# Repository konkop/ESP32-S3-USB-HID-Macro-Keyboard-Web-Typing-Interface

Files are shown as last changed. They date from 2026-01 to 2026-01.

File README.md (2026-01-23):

# ESP32-S3 USB HID Macro Keyboard + Web Typing Interface

This project turns an ESP32-S3 into a USB HID keyboard with a built-in web interface that can type text into another computer in a human-like way and trigger macro commands using physical Cherry MX keys.
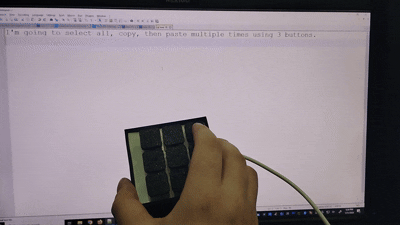
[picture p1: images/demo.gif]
Demo

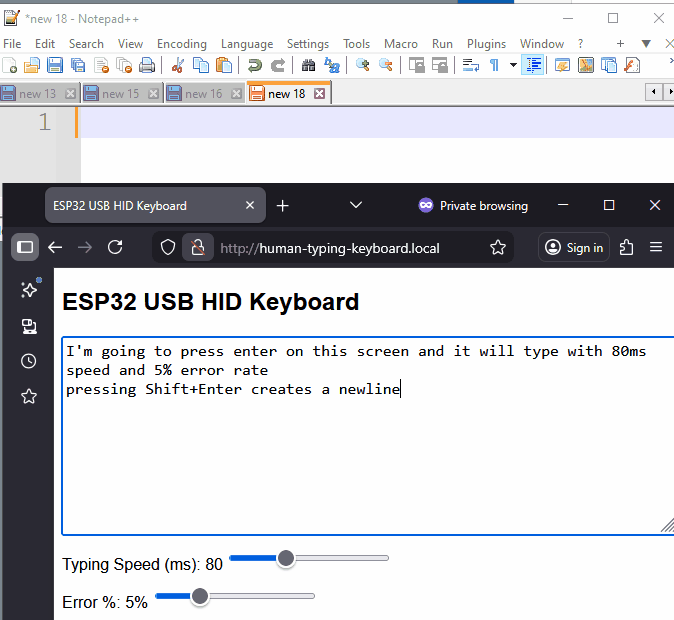
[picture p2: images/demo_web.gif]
Demo2

---

## Features

- USB HID Keyboard (TinyUSB)
- No drivers needed on destination machine so works on any OS(literally everything: Windows, Linux, Mac, Android, Chrome OS, smart TVs, etc.)
- Web interface hosted on the ESP32
- Press Enter to send text (Shift+Enter inserts newline)
- Human-like typing (random delays, pauses, backspaces)
- 9 physical Cherry MX macro keys
- Can skip physical keys for just remote typing
- Debounced button handling
- Serial debug output
- mDNS support (.local address)
- PlatformIO compatible

---

## Hardware Required

### Main Board
- ESP32-S3 development board with native USB
- Tested with: ESP32-S3 DevKit (N16R8)
  - https://www.amazon.com/dp/B0CKXJLP4B

### Buttons
- 9x Cherry MX switches
  - https://www.amazon.com/dp/B0DSHTPSL3
- Optional keycaps

### Wiring
- Jumper wires
- USB-C data cables (must support data, not power-only)

---

## GPIO Pin Mapping (Physical Keys)

Each Cherry MX switch connects between a GPIO pin and GND.
Internal pull-ups are used (INPUT_PULLUP).

| Button | GPIO | Action |
|---|---|---|
| 1 | GPIO 4 | Ctrl + C |
| 2 | GPIO 5 | Ctrl + V |
| 3 | GPIO 12 | Ctrl + A |
| 4 | GPIO 13 | KEEP ALIVE -> www.google.com (win only) |
| 5 | GPIO 14 | Alt + Tab |
| 6 | GPIO 15 | Ctrl + X |
| 7 | GPIO 16 | Ctrl + Alt + Del (delay) enter |
| 8 | GPIO 17 | Ctrl + S |
| 9 | GPIO 18 | Ctrl + P |

### Wiring Diagram (Concept)

GPIO ----[ Cherry MX Switch ]---- GND

- Button pressed = LOW
- Button released = HIGH
- No external resistors required

---

## Software Setup (PlatformIO)

### Install Tools
- Visual Studio Code
- PlatformIO extension
---

## Wi-Fi Configuration

Edit main.cpp and set your Wi-Fi credentials:

const char* ssid = "YOUR_WIFI_NAME";
const char* password = "YOUR_WIFI_PASSWORD";

---

## Uploading and Running

### USB Connections

- UART / COM port: flashing firmware and Serial Monitor
- Native USB port: HID keyboard device

Both ports can be connected to the same computer at the same time.

### Upload Firmware

Use PlatformIO "Upload".

### Serial Monitor

Use PlatformIO "Monitor".

Expected output:

WiFi Connected
IP Address: xxx.xxx.xxx.xxx
http://human-typing-keyboard.local

---

## Web Interface

Open the following in your browser:

http://human-typing-keyboard.local

- Press Enter to send text and clears the textbox
- Shift + Enter inserts a newline

---

## Physical Macro Keys

- Each key triggers once per press
- Fully debounced in software
- Serial output confirms key presses

---

## Debugging Notes

- Buttons are active LOW
- HIGH = unpressed
- LOW = pressed
- Use Serial output to verify wiring

---

## Notes

- ESP32-S3 supports 2.4 GHz Wi-Fi only
- Many USB-C cables are power-only — use data-capable cables
- HID typing controls your computer — use with caution
- This is built as a demonstration use at your own risk. I take no responsiblity for actions with this device.

---

## Future Improvements

- Web-configurable macros
- Key remapping
- OLED display support

---

## License

MIT License

---

## Credits

- ESP32 Arduino Core
- TinyUSB
- PlatformIO

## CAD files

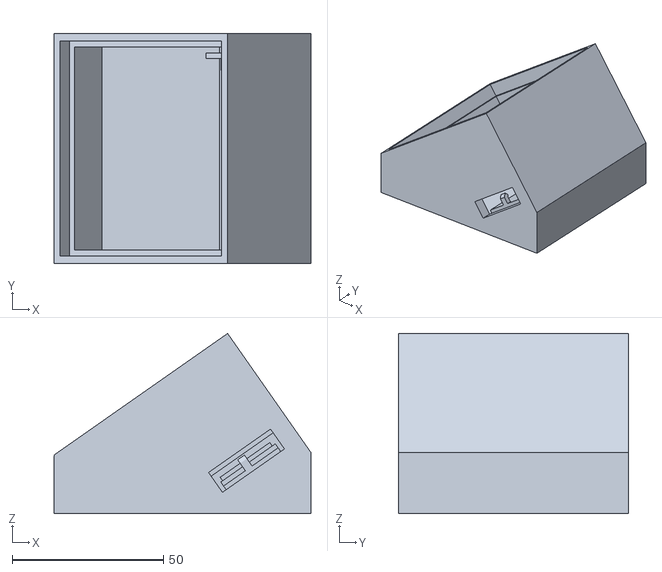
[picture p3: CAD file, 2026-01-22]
ENCLOSURE/body.stl
84.9 x 76.0 x 59.5

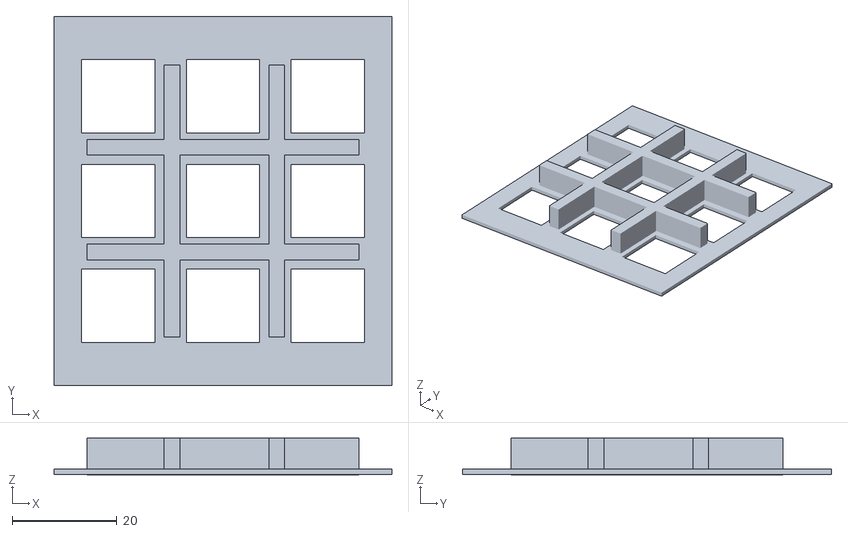
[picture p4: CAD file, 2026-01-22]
ENCLOSURE/key panel.stl
64.5 x 70.5 x 7.00

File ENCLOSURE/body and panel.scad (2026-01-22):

showBody=true;
showPanel=false;

//panel
if(showPanel){
    difference(){
    cube([70-5-.5,76-5-.5,1]);

    translate([5.25,8.25,0])
    for (row = [1 : 3])
        for (col = [1 : 3]) {
            translate([(col-1)*20, (row-1)*20, -.1])
            cube([14,14,6]);
        }
    }
    for (col = [1 : 2]) {
        translate([(col-1)*20+21, 9.25, -.1])
        cube([3,52,7]);
        
        
        translate([6.25, (col-1)*20+27, -.1])
        rotate([0,0,-90])
        cube([3,52,7]);
    }
}


//The main body
if(showBody){
union(){
    hull(){
    cube([1,76,1]);
    translate([0,0,18])
    cube([1,76,1]);
    translate([18,0,0])
    cube([1,76,1]);
    }
    hull(){
    translate([83.85,0,0])
    cube([1,76,1]);
    translate([83.85,0,19.2])
    cube([1,76,1]);

    translate([55,0,0])
    cube([1,76,1]);
    }



    cube([83.85,76,4.5]);

    translate([27.5,0,-20])
    rotate([0,-35,0])
    union(){
        difference(){
            cube([70,76,48]);
            //main cutout
            translate([9/2,9/2,4.5])
            cube([70-9,76-9,48-4.4]);
            
            //lip for cover
            translate([5/2,5/2,48-5.49])
            cube([70-5,76-5,5.5]);
            
            //usb cutout
            translate([70-25-7.5,-.1,4])
            cube([28,10,12]);
            
            //45 on main box
            translate([0,-.1,-70])
            rotate([0,-55,0])
            cube([80,80,80]);
        }
        //board
        translate([70-5,4.5,4])
        rotate([0,0,90])
        union(){
            baseheight=.5;
            basewidth=65;
            cube([basewidth,28.5,baseheight]);
            translate([0,(28.5-22.5)/2,0])
            cube([basewidth-5.8,22,3+baseheight]);
            translate([basewidth-5.8,(28.5-22.5)/2,0])
            cube([4,22,3+baseheight+1.6]);


            //end board
            translate([basewidth-5.8,(28.5-22.5)/2,0])
            cube([4,18,3+baseheight+1.6]);
            translate([basewidth-5.8+4,0,0])
            difference(){
                cube([1.8,28.5,3+baseheight+5]);
                translate([-.1,(28.5-20)/2,3+baseheight+1.5])
                cube([3,20,1.5]);
            }

            //front board clip
            translate([0,29/2-1,3+baseheight])
            union(){
                cube([2,2.7,3]); 
                translate([0,0,3])   
                rotate([0,45,0])
                cube([1.7,2.7,2]);
            }
        }
    }
}
}

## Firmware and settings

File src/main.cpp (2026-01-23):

#include <Arduino.h>
#include <WiFi.h>
#include <WebServer.h>

#include "USB.h"
#include "USBHIDKeyboard.h"
#include <ESPmDNS.h>

const int NUM_BUTTONS = 9;
const int debounceDelay = 200; // milliseconds

int buttonPins[NUM_BUTTONS] = {4,5,12,13,14,15,16,17,18};
bool lastButtonState[NUM_BUTTONS];
unsigned long lastDebounceTime[NUM_BUTTONS];
bool typingInProgress = false;

int typingSpeedMs = 80;     // base delay between keystrokes
int errorPercent = 5;      // percent chance of typo

bool keepAliveEnabled = false;
unsigned long lastKeepAliveTime = 0;
const unsigned long KEEP_ALIVE_INTERVAL = 5UL * 60UL * 1000UL; // 5 minutes

// ================= USB HID ================= 

USBHIDKeyboard Keyboard;

// ================= WIFI ================= 

const char* ssid = "YOUR_WIFI_NAME";
const char* password = "YOUR_WIFI_PASSWORD";

WebServer server(80);

String textBuffer;
bool startTyping = false;

// ================= HTML ================= 

const char* htmlPage = R"rawliteral(
<!DOCTYPE html>
<html>
<head>
  <title>ESP32 USB HID Keyboard</title>
  <style>
    body { font-family: Arial; }
    textarea { width: 100%; font-size: 16px; }
    .slider-container { margin-top: 10px; }
    label { display: block; margin-top: 10px; }
  </style>

  <script>
    document.addEventListener("DOMContentLoaded", function() {
      const textarea = document.getElementById("inputText");
      const speedSlider = document.getElementById("speed");
      const errorSlider = document.getElementById("error");
      const speedValue = document.getElementById("speedValue");
      const errorValue = document.getElementById("errorValue");

      speedValue.textContent = speedSlider.value;
      errorValue.textContent = errorSlider.value;

      speedSlider.oninput = () => speedValue.textContent = speedSlider.value;
      errorSlider.oninput = () => errorValue.textContent = errorSlider.value;

      textarea.addEventListener("keydown", function(e) {
        if (e.key === "Enter" && !e.shiftKey) {
          e.preventDefault();
          sendText();
        }
      });

      function sendText() {
        const text = textarea.value;
        if (!text || text.trim().length === 0) return;

        const params =
          "text=" + encodeURIComponent(text) +
          "&speed=" + speedSlider.value +
          "&error=" + errorSlider.value;

        var xhr = new XMLHttpRequest();
        xhr.open("POST", "/send", true);
        xhr.setRequestHeader("Content-type", "application/x-www-form-urlencoded");
        xhr.send(params);

        textarea.value = "";
        textarea.focus();
      }
    });
  </script>
</head>

<body>
  <h2>ESP32 USB HID Keyboard</h2>

  <textarea id="inputText" rows="10"
    placeholder="Enter = send | Shift+Enter = newline"></textarea>

  <div class="slider-container">
    <label>
      Typing Speed (ms): <span id="speedValue"></span>
      <input type="range" id="speed" min="20" max="200" value="80">
    </label>

    <label>
      Error %: <span id="errorValue"></span>%
      <input type="range" id="error" min="0" max="20" value="5">
    </label>
  </div>
</body>
</html>
)rawliteral";


// ================= HUMAN TYPING ================= 

void runKeepAlive() {
  Serial.println("KEEP ALIVE: Launching Edge");

  // Win + R
  Keyboard.press(KEY_LEFT_GUI);
  Keyboard.press('r');
  Keyboard.releaseAll();
  delay(300);

  // Type Edge command
  Keyboard.print("msedge https://www.google.com");
  delay(100);

  // Enter
  Keyboard.press(KEY_RETURN);
  Keyboard.release(KEY_RETURN);
}

void humanDelay() {
  int jitter = random(-typingSpeedMs / 3, typingSpeedMs / 3);
  delay(max(10, typingSpeedMs + jitter));
}

void typeChar(char c) {
  Keyboard.print(c);
}

void backspace() {
  Keyboard.press(KEY_BACKSPACE);
  delay(10);
  Keyboard.release(KEY_BACKSPACE);
}

void humanType(const String& text) {
  for (int i = 0; i < text.length(); i++) {
    humanDelay();

    char c = text[i];

    // 5% typo chance only for letters
    if (random(0, 100) < errorPercent && isalpha(c)) {
      Keyboard.print('x');
      delay(random(40, 120));
      Keyboard.press(KEY_BACKSPACE);
      Keyboard.release(KEY_BACKSPACE);
    }

    if (c == '\n') {
      Keyboard.press(KEY_RETURN);
      delay(10);
      Keyboard.release(KEY_RETURN);
    } else {
      typeChar(c);
    }

    // Natural pauses
    if (c == '.' || c == ',')
      delay(random(300, 700));
    if (c == '\n')
      delay(random(500, 1000));
  }
}

// Map buttons to HID actions (example: Ctrl+C, Ctrl+V...)
void triggerAction(int btn) {

  // ANY button press cancels keep-alive
  if (keepAliveEnabled && btn != 3) {
    keepAliveEnabled = false;
    Serial.println("KEEP ALIVE DISABLED (button activity)");
    return;
  }

  switch (btn) {
    case 0: //button 1
      Serial.println("Button 1 pressed: Ctrl+C");
      Keyboard.press(KEY_LEFT_CTRL);
      Keyboard.press('c');
      delay(50);
      Keyboard.releaseAll();
      break;
    case 1: // Button 2
      Serial.println("Button 2 pressed: Ctrl+V");
      Keyboard.press(KEY_LEFT_CTRL);
      Keyboard.press('v');
      delay(50);
      Keyboard.releaseAll();
      break;
    case 2:// Button 3
      Serial.println("Button 3 pressed: Ctrl+A (Select All)");
      Keyboard.press(KEY_LEFT_CTRL);
      Keyboard.press('a');
      delay(50);
      Keyboard.releaseAll();
      break;
    case 3: // BUTTON 4 → KEEP ALIVE Toggle
      keepAliveEnabled = !keepAliveEnabled;
      lastKeepAliveTime = millis();
      Serial.println("KEEP ALIVE changed");
      break;

    case 4: // BUTTON 5 → Alt + tab
      Keyboard.press(KEY_LEFT_ALT);
      Keyboard.press(KEY_TAB);
      delay(100);
      Keyboard.releaseAll();
      break;
    case 5:
      Serial.println("Button 6 pressed: Ctrl+X (Cut)");
      Keyboard.press(KEY_LEFT_CTRL);
      Keyboard.press('x');
      delay(50);
      Keyboard.releaseAll();
      break;
    case 6:
      Serial.println("Button 7 pressed: Ctrl+Alt+Delete, wait 2s, Enter");

      // Ctrl + Alt + Delete
      Keyboard.press(KEY_LEFT_CTRL);
      Keyboard.press(KEY_LEFT_ALT);
      Keyboard.press(KEY_DELETE);
      delay(100);
      Keyboard.releaseAll();

      // Wait 2 seconds
      delay(2000);

      // Press Enter
      Keyboard.press(KEY_RETURN);
      delay(50);
      Keyboard.release(KEY_RETURN);

      break;
    case 7:
      Serial.println("Button 8 pressed: Ctrl+S (Save)");
      Keyboard.press(KEY_LEFT_CTRL);
      Keyboard.press('s');
      delay(50);
      Keyboard.releaseAll();
      break;
    case 8:
      Serial.println("Button 9 pressed: Ctrl+P (Print)");
      Keyboard.press(KEY_LEFT_CTRL);
      Keyboard.press('p');
      delay(50);
      Keyboard.releaseAll();
      break;
  }
}


// ================= WEB HANDLERS ================= 

void handleRoot() {
  server.send(200, "text/html", htmlPage);
}

void handleSend() {
  textBuffer = server.arg("text");

  if (server.hasArg("speed")) {
    typingSpeedMs = server.arg("speed").toInt();
  }

  if (server.hasArg("error")) {
    errorPercent = server.arg("error").toInt();
  }

  Serial.printf(
    "Received text (%d chars), speed=%dms, error=%d%%\n",
    textBuffer.length(),
    typingSpeedMs,
    errorPercent
  );

  startTyping = true;
  server.send(200, "text/plain", "OK");
}

// ================= SETUP ================= 

void setup() {
  delay(1000);

  Serial.begin(115200);       // Start the Serial Monitor
  while (!Serial) { }         // Wait for Serial to be ready (optional)
  
  Serial.println("Booting ESP32-S3...");
  
  // USB HID
  Keyboard.begin();
  USB.begin();

  WiFi.setHostname("human-typing-keyboard");

  //start wifi
  WiFi.begin(ssid, password);
  Serial.print("Connecting to Wi-Fi ");

  //keep trying wifi
  int retries = 0;
  while (WiFi.status() != WL_CONNECTED) {
      delay(500);
      Serial.print(".");
      retries++;
      if (retries > 20) {  // timeout after 10 seconds
          Serial.println("\nFailed to connect to Wi-Fi!");
          break;
      }
  }

  if (WiFi.status() == WL_CONNECTED) {
      Serial.println("\nWi-Fi Connected!");
      Serial.print("IP Address: ");
      Serial.println(WiFi.localIP());
  }

  //turn on the web server
  server.on("/", handleRoot);
  server.on("/send", HTTP_POST, handleSend);
  server.begin();

  // setup http://human-typing-keyboard.local
  MDNS.begin("human-typing-keyboard");

  for (int i = 0; i < NUM_BUTTONS; i++) {
    pinMode(buttonPins[i], INPUT_PULLUP);
    lastButtonState[i] = HIGH;  // buttons idle HIGH
    lastDebounceTime[i] = 0;
  }

}

// ================= LOOP ================= 

void loop() {
  server.handleClient();

  if (startTyping && !typingInProgress) {
    typingInProgress = true;
    String textToType = textBuffer;  // copy
    startTyping = false;              // reset immediately
    delay(500);                       // optional focus delay
    humanType(textToType);
    typingInProgress = false;
  }

  for (int i = 0; i < NUM_BUTTONS; i++) {
    int reading = digitalRead(buttonPins[i]);

    // If the reading changed, reset the debounce timer
    if (reading == LOW) {
      if ((millis() - lastDebounceTime[i]) > debounceDelay) {
        lastDebounceTime[i] = millis();
        triggerAction(i); // prints to Serial & sends HID keys
      }

    }

    lastButtonState[i] = reading;
  }
  if (keepAliveEnabled) {
    unsigned long now = millis();

    if (now - lastKeepAliveTime >= KEEP_ALIVE_INTERVAL) {
      Serial.println("\nrunning browser");
      lastKeepAliveTime = now;
      runKeepAlive();
    }
  }
}

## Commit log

2026-01-21 Enhance README with project details and instructions
    Expanded the README to include detailed project features, hardware requirements, GPIO pin mapping, software setup instructions, and debugging notes.
2026-01-21 Modify GPIO actions and add usage disclaimer
    Updated GPIO button actions and added a disclaimer about usage risks.
2026-01-21 Add Amazon link for ESP32-S3 DevKit
2026-01-21 Update README with driverless operation feature
    Added a feature note about driverless operation on any OS.
2026-01-22 Modify platformio.ini for ESP32-S3 settings
    Updated platformio.ini configuration for ESP32-S3.
2026-01-22 Initial release: ESP32-S3 HID macro keyboard with web typing interface
    [body and panel.scad, body.stl, key panel.stl]
